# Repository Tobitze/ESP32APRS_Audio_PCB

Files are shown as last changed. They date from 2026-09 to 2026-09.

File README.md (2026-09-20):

This is a PCB for my APRS BLE TNC, which is based on the ESP32APRS_Audio Firmware from nakhonthai - see https://github.com/nakhonthai/ESP32APRS_Audio.
This PCB implements the basic components to work with an esp32s3 and an external handheld Radio, like filters and DC Offsets. The Radio is connected via the Kenwood Plug. This is not intended for an RF Module on the Board!
It's oriented around Nakhonthai's layouts with some small changes.
I designed it for my esp32s3-N16R8 (the one already on a PCB, not the chip itself). Please check your Pin configuration before using this.

TODO: This PCB has three UART Connectors, but no I2C für WX Sensors. You can reconfigure one of them, but the pin Layout then needs one wire on the pcb.

This PCB has:

-NPN transistor for PTT control

-GPIO PWM Filters (Audio Output)

-ADC Input DC Bias (Audio Input)

-UART Connectors for external GPS PCBs and other stuff (Supposed to be under the Board)

-Connectors for simple three-pin Sensors

-Every other Pin of the esp32 is led out to some connectors for future extensions, including four power pins

If you don't want to order this for yourself, get in touch; maybe I still have some lying around. (See qrz.com for email address)

73 de
DC4TA





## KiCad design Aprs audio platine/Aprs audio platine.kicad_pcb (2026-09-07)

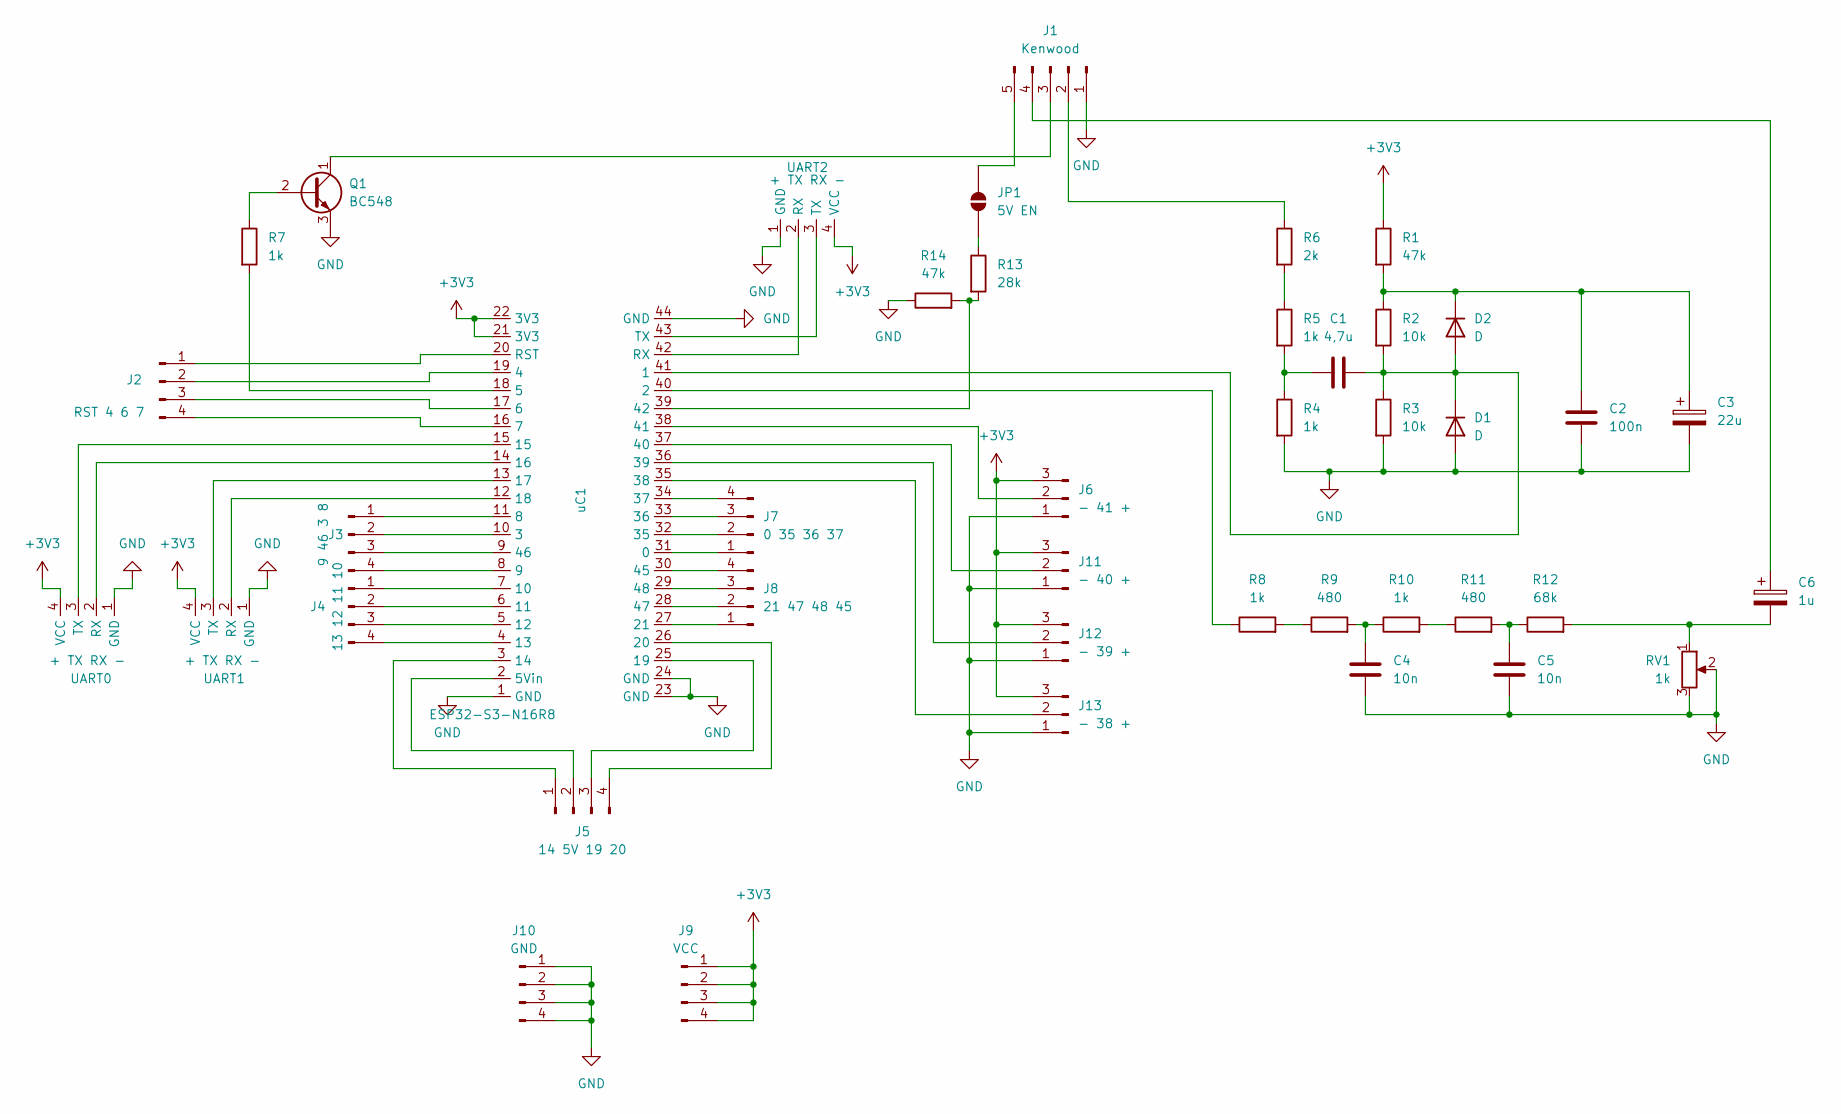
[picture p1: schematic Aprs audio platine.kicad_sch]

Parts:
C1: 4,7u; C_Disc_D3.0mm_W2.0mm_P2.50mm
C2: 100n; C_Disc_D3.0mm_W2.0mm_P2.50mm
C3: 22u; CP_Radial_D5.0mm_P2.50mm
C4, C5: 10n; C_Disc_D3.0mm_W2.0mm_P2.50mm
C6: 1u; CP_Radial_D5.0mm_P2.50mm
D1, D2: D; D_DO-34_SOD68_P7.62mm_Horizontal
J1: Kenwood; SolderWire-0.25sqmm_1x05_P4.2mm_D0.65mm_OD1.7mm
J2: RST 4 6 7; PinHeader_1x04_P2.54mm_Vertical
J3: 9 46 3 8; PinHeader_1x04_P2.54mm_Vertical
J4: 13 12 11 10; PinHeader_1x04_P2.54mm_Vertical
J5: 14 5V 19 20; PinHeader_1x04_P2.54mm_Vertical
J6: - 41 +; PinHeader_1x03_P2.54mm_Vertical
J7: 0 35 36 37; PinHeader_1x04_P2.54mm_Vertical
J8: 21 47 48 45; PinHeader_1x04_P2.54mm_Vertical
J9: VCC; PinHeader_1x04_P2.54mm_Vertical
J10: GND; PinHeader_1x04_P2.54mm_Vertical
J11: - 40 +; PinHeader_1x03_P2.54mm_Vertical
J12: - 39 +; PinHeader_1x03_P2.54mm_Vertical
J13: - 38 +; PinHeader_1x03_P2.54mm_Vertical
JP1: 5V EN; SolderJumper-2_P1.3mm_Open_RoundedPad1.0x1.5mm
Q1: BC548; TO-92_Inline
R1, R14: 47k; R_Axial_DIN0309_L9.0mm_D3.2mm_P12.70mm_Horizontal
R2, R3: 10k; R_Axial_DIN0309_L9.0mm_D3.2mm_P12.70mm_Horizontal
R4, R5, R7, R8, R10: 1k; R_Axial_DIN0309_L9.0mm_D3.2mm_P12.70mm_Horizontal
R6: 2k; R_Axial_DIN0309_L9.0mm_D3.2mm_P12.70mm_Horizontal
R9, R11: 480; R_Axial_DIN0309_L9.0mm_D3.2mm_P12.70mm_Horizontal
R12: 68k; R_Axial_DIN0309_L9.0mm_D3.2mm_P12.70mm_Horizontal
R13: 28k; R_Axial_DIN0309_L9.0mm_D3.2mm_P12.70mm_Horizontal
RV1: 1k; TerminalBlock_MetzConnect_Type055_RT01503HDWU_1x03_P5.00mm_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
UART0, UART1, UART2: + TX RX -; NEO-6M-Board
uC1: ESP32-S3-N16R8; esp32s3board

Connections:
+3V3: J6.3, J9.1, J9.2, J9.3, J9.4, J11.3, J12.3, J13.3, R1.1, UART0.4 (VCC), UART1.4 (VCC), UART2.4 (VCC), uC1.21 (3V3), uC1.22 (3V3)
GND: C2.2, C3.2, C4.2, C5.2, D1.2 (A), J1.1, J6.1, J10.1, J10.2, J10.3, J10.4, J11.1, J12.1, J13.1, Q1.3 (E), R3.2, R4.2, R14.1, RV1.2, RV1.3, UART0.1 (GND), UART1.1 (GND), UART2.1 (GND), uC1.1 (GND), uC1.23 (GND), uC1.24 (GND), uC1.44 (GND)
unnamed: C1.1, R4.1, R5.2
unnamed: C4.1, R9.2, R10.1
unnamed: C5.1, R11.2, R12.1
unnamed: C6.2, R12.2, RV1.1
unnamed: C1.2, D1.1 (K), D2.2 (A), R2.2, R3.1, uC1.41 (1)
unnamed: C2.1, C3.1, D2.1 (K), R1.2, R2.1
unnamed: J1.2, R6.1
unnamed: J1.3, Q1.1 (C)
unnamed: C6.1, J1.4
unnamed: J1.5, JP1.2 (B)
unnamed: J2.1, uC1.20 (RST)
unnamed: J2.2, uC1.19 (4)
unnamed: J2.3, uC1.17 (6)
unnamed: J2.4, uC1.16 (7)
unnamed: J3.1, uC1.11 (8)
unnamed: J3.2, uC1.10 (3)
unnamed: J3.3, uC1.9 (46)
unnamed: J3.4, uC1.8 (9)
unnamed: J4.1, uC1.7 (10)
unnamed: J4.2, uC1.6 (11)
unnamed: J4.3, uC1.5 (12)
unnamed: J4.4, uC1.4 (13)
unnamed: J5.1, uC1.3 (14)
unnamed: J5.2, uC1.2 (5Vin)
unnamed: J5.3, uC1.25 (19)
unnamed: J5.4, uC1.26 (20)
unnamed: J6.2, uC1.38 (41)
unnamed: J7.1, uC1.31 (0)
unnamed: J7.2, uC1.32 (35)
unnamed: J7.3, uC1.33 (36)
unnamed: J7.4, uC1.34 (37)
unnamed: J8.1, uC1.27 (21)
unnamed: J8.2, uC1.28 (47)
unnamed: J8.3, uC1.29 (48)
unnamed: J8.4, uC1.30 (45)
unnamed: J11.2, uC1.37 (40)
unnamed: J12.2, uC1.36 (39)
unnamed: J13.2, uC1.35 (38)
unnamed: JP1.1 (A), R13.1
unnamed: Q1.2 (B), R7.1
unnamed: R5.1, R6.2
unnamed: R8.2, R9.1
unnamed: R10.2, R11.1
unnamed: UART0.2 (RX), uC1.14 (16)
unnamed: UART0.3 (TX), uC1.15
unnamed: UART1.2 (RX), uC1.12 (18)
unnamed: UART1.3 (TX), uC1.13 (17)
unnamed: UART2.2 (RX), uC1.42 (RX)
unnamed: UART2.3 (TX), uC1.43 (TX)
unnamed: R8.1, uC1.40 (2)
unnamed: R7.2, uC1.18 (5)
unnamed: R13.2, R14.2, uC1.39 (42)

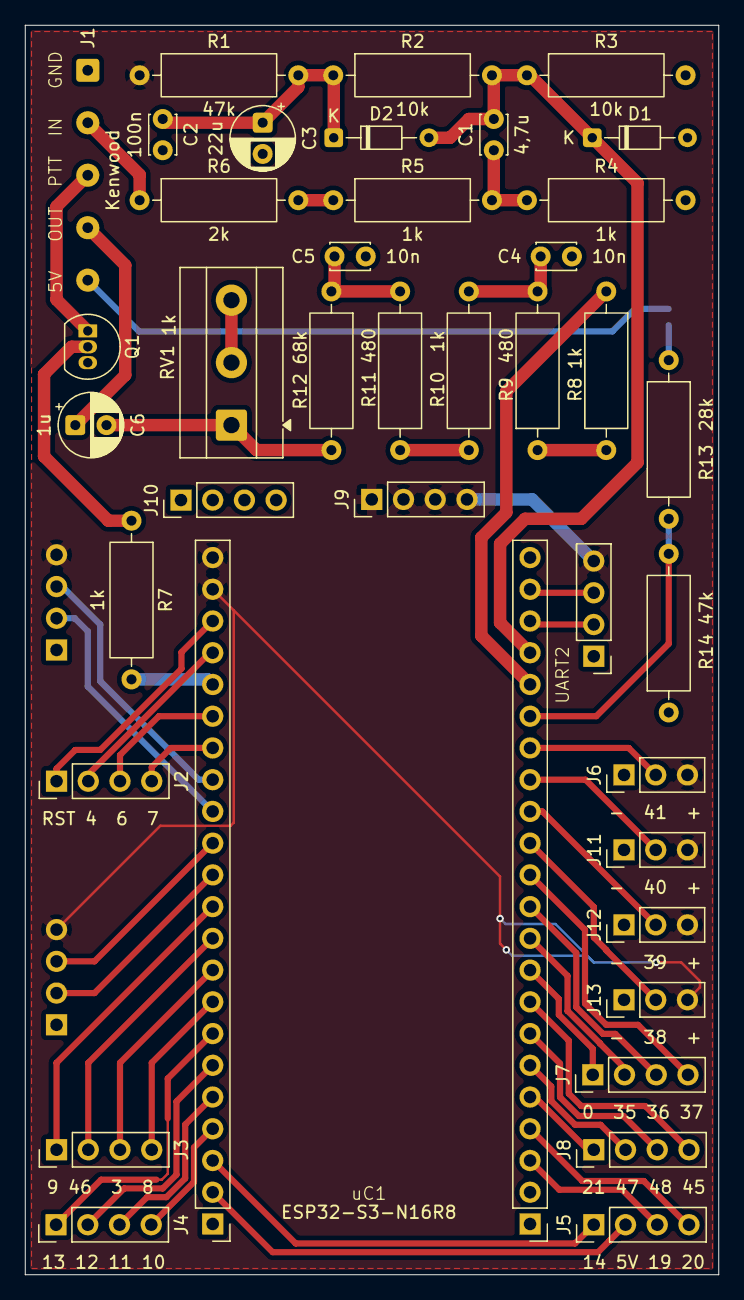
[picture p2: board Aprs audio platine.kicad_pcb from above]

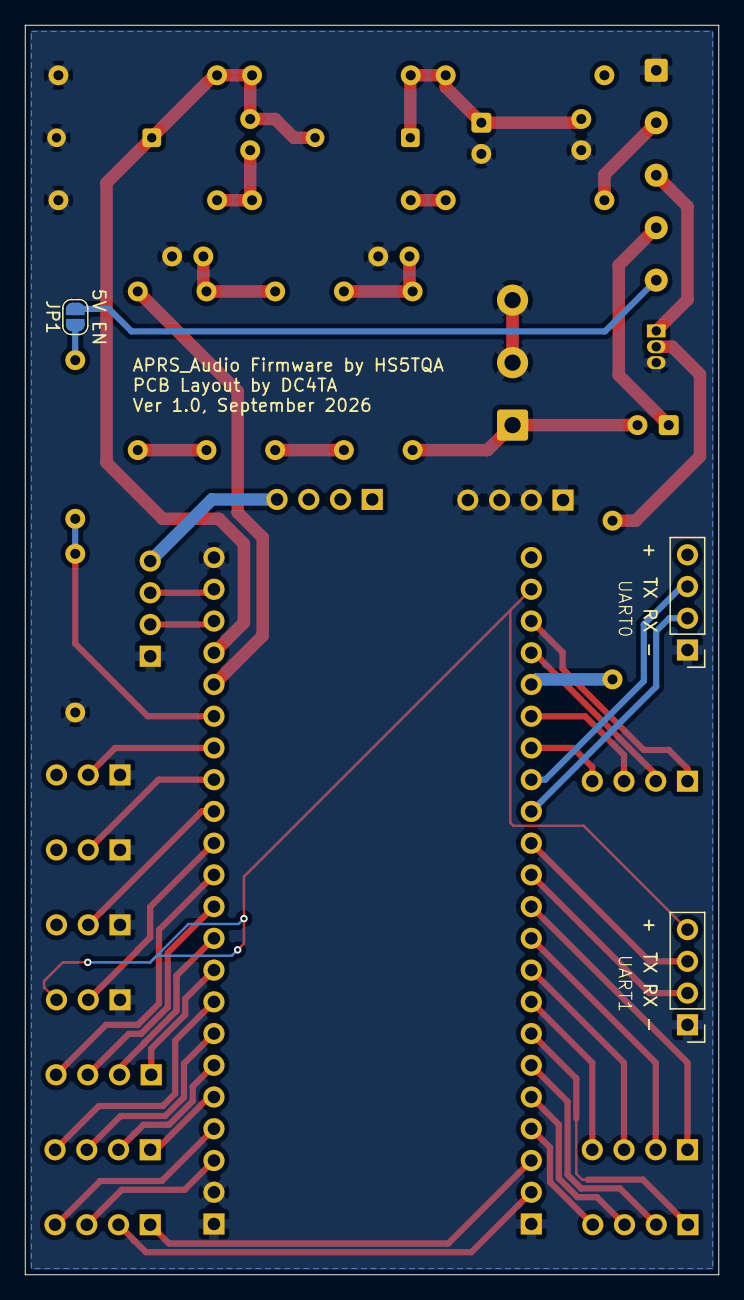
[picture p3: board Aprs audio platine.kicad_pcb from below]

Board: 2 copper layers, 55.5 x 100.0 mm, 42 parts (3 on the bottom side), 54 nets.
